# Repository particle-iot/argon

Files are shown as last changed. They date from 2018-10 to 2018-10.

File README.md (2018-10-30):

# Argon

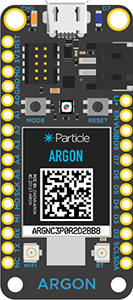
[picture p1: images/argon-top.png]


### Overview

The Argon is a powerful Wi-Fi enabled development board that can act as either a standalone Wi-Fi endpoint or Wi-Fi enabled gateway for Particle Mesh networks. It is based on the Nordic nRF52840 and has built-in battery charging circuitry so it’s easy to connect a Li-Po and deploy your local network in minutes.

The Argon is great for connecting existing projects to the Particle Device Cloud or as a gateway to connect an entire group of local endpoints.

### Features

* Espressif ESP32-D0WD 2.4Ghz Wi-Fi coprocessor 
  * On-board 4MB flash for ESP32 
  * 802.11 b/g/n support 
  * 802.11 n (2.4 GHz), up to 150 Mbps
* Nordic Semiconductor nRF52840 SoC 
  * ARM Cortex-M4F 32-bit processor @ 64MHz 
  * 1MB flash, 256KB RAM 
  * IEEE 802.15.4-2006: 250 Kbps 
  * Bluetooth 5: 2 Mbps, 1 Mbps, 500 Kbps, 125 Kbps 
  * Supports DSP instructions, HW accelerated Floating Point Unit (FPU) calculations 
  * ARM TrustZone CryptoCell-310 Cryptographic and security module 
  * Up to +8 dBm TX power (down to -20 dBm in 4 dB steps) 
  * NFC-A tag
* On-board additional 2MB SPI flash
* 20 mixed signal GPIO (6 x Analog, 8 x PWM), UART, I2C, SPI
* Micro USB 2.0 full speed (12 Mbps)
* Integrated Li-Po charging and battery connector
* JTAG (SWD) Connector
* RGB status LED
* Reset and Mode buttons
* On-board PCB antenna
* u.FL connector for external antenna
* Meets the Adafruit Feather [specification](https://learn.adafruit.com/adafruit-feather/feather-specification) in dimensions and pinout
* FCC, CE and IC certified
* RoHS compliant (lead-free)

### Structure of this repository:
 - /eagle
     + Contains the schematic and PCB files in the Eagle file format
 - /gerbers
     + Contains the manufacturing gerber files for the board
 - /datasheets
     + Contains the relevant datasheets of the components used on the Argon
 - /pdfs
     + Contains schematic files in PDF 

### Hardware datasheet

The complete datasheet for the Argon is available [here.](https://docs.particle.io/datasheets/wi-fi/argon-datasheet/)

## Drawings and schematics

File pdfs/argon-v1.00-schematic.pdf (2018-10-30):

# 15nH MICRO_USB_5P

# CARGB C²¹

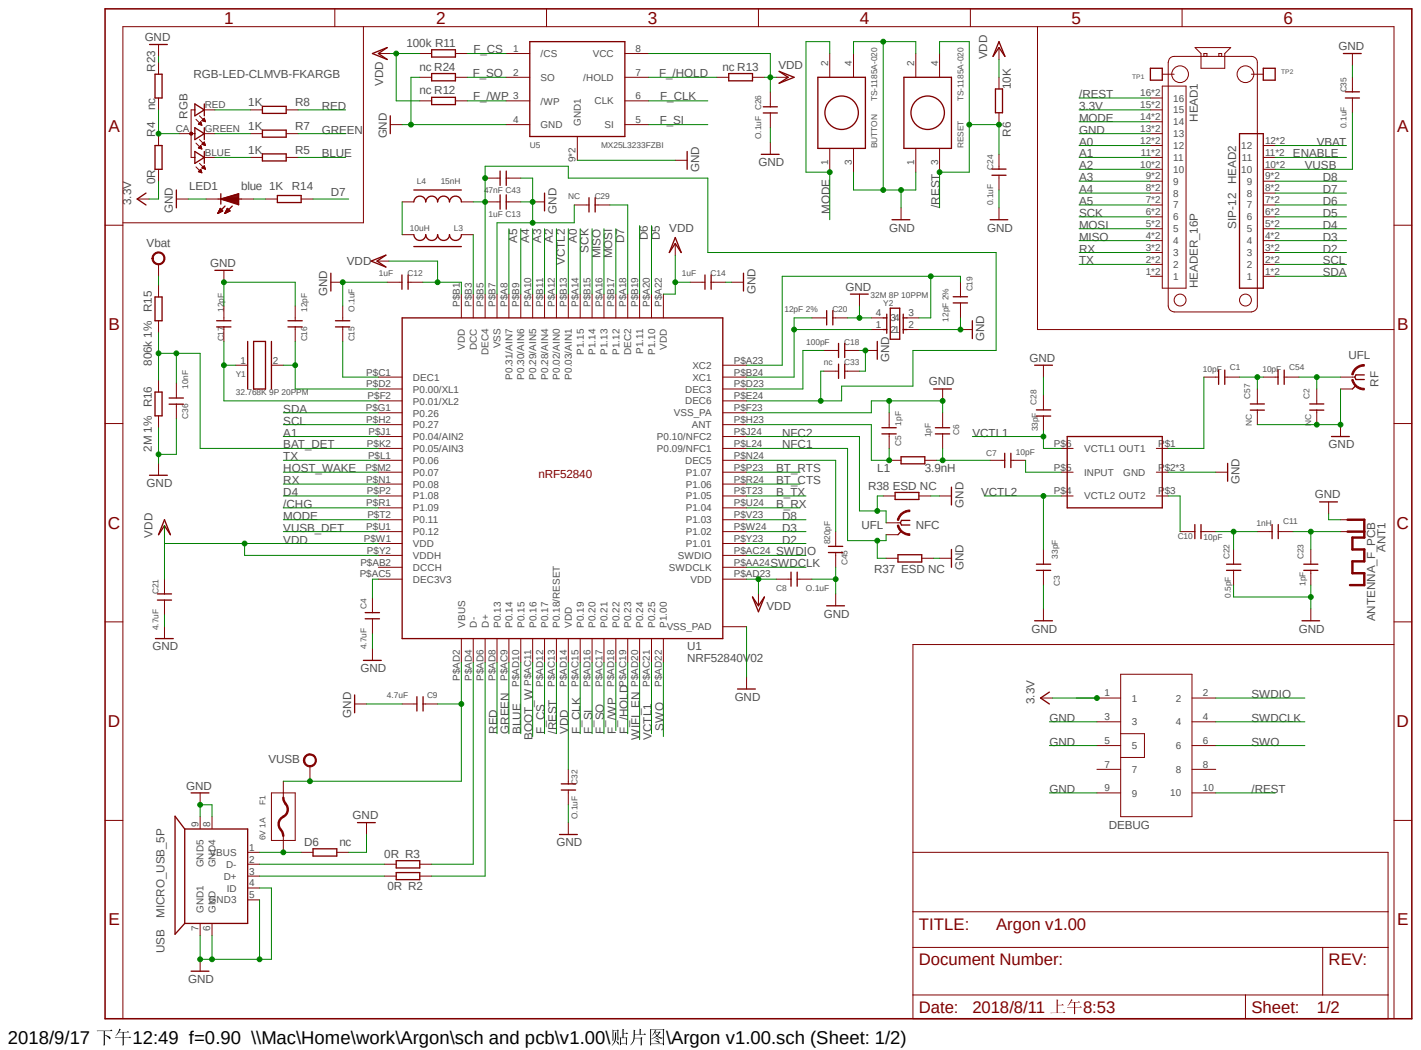
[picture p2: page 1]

GND | | GND

RGB-LED-CLMVB-FKARGB

Document Number: | REV:

Date: 2018/8/11 8:53 | Sheet: 1/2

GND | O.1uF
nc | 10K

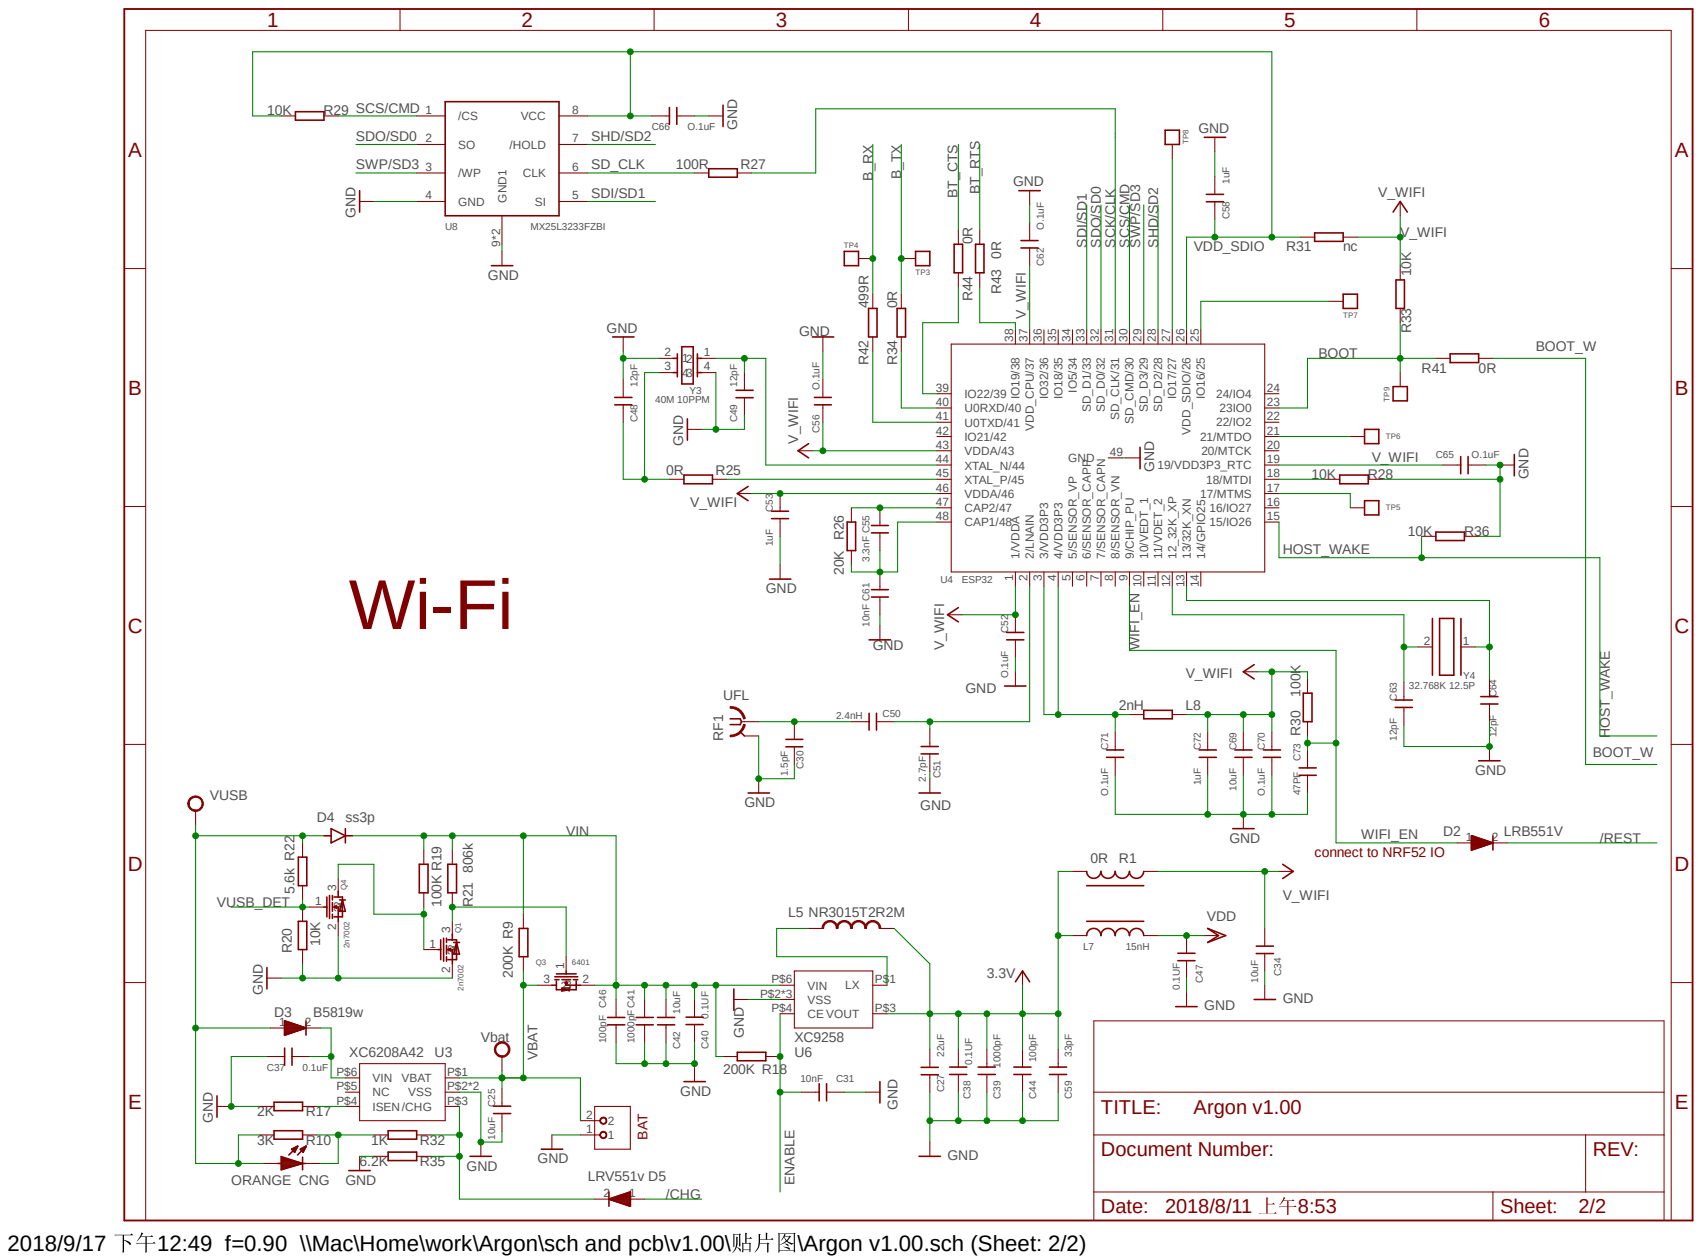
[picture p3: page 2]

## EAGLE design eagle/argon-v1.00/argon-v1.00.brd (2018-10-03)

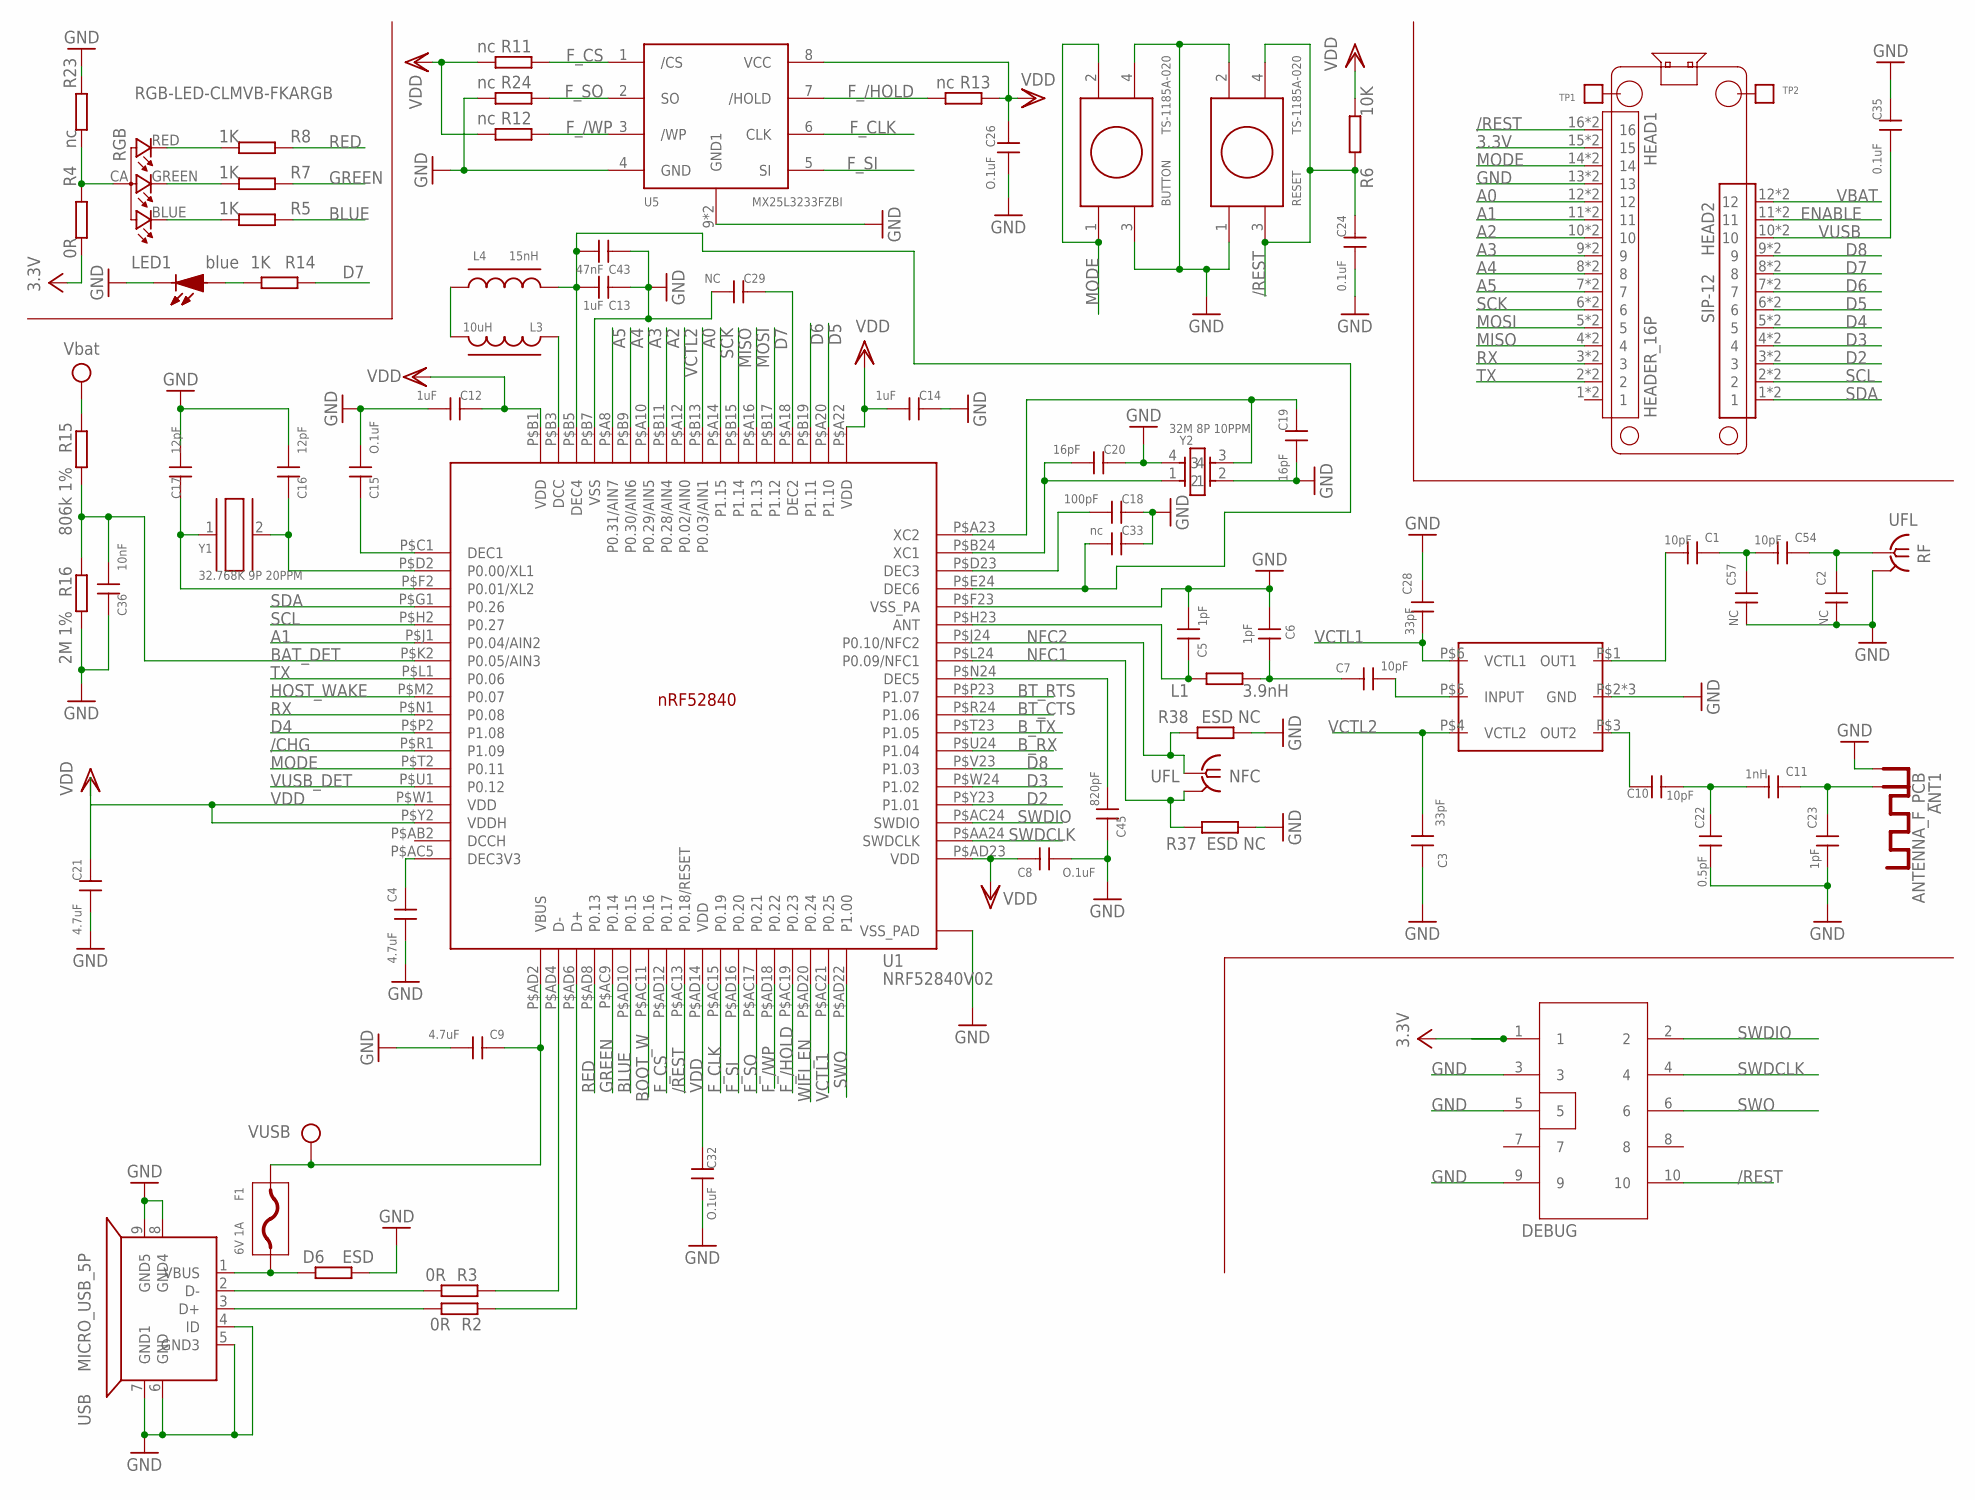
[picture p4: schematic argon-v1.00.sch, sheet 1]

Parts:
ANT1: ANTENNA_F_PCB
BUTTON: TS-1185A-020
C1, C7, C10, C54: 10pF; C-0402
C2, C29, C57: NC; C-0402
C3, C28: 33pF; C-0402
C4, C9, C21: 4.7uF; C-0402
C5, C6, C23: 1pF; C-0402
C8, C15, C26, C32: O.1uF; C-0402
C11: 1nH; C-0402
C12, C13, C14: 1uF; C-0402
C16, C17: 12pF; C-0402
C18: 100pF; C-0402
C19, C20: 16pF; C-0402
C22: 0.5pF; C-0402
C24, C35: 0.1uF; C-0402
C33: nc; C-0402
C36: 10nF; C-0402
C43: 47nF; C-0402
C45: 820pF; C-0402
D6: ESD; R-0402S
DEBUG: CON5X2; CON5X2_1.27
F1: 6V 1A; F0805
HEAD1: HEADER_16P; HEADER_16P2.54
HEAD2: SIP-12
L1: 3.9nH; R-0402S
L3: 10uH; R-0603A
L4: 15nH; R-0402S
LED1: blue; LED0603
NFC: UFL; IPEX-20279-001E
R2, R3, R4: 0R; R-0402S
R5, R7, R8, R14: 1K; R-0402S
R6: 10K; R-0402S
R11, R12, R13, R23, R24: nc; R-0402S
R15: 806k 1%; R-0402S
R16: 2M 1%; R-0402S
R37, R38: ESD NC; R-0402S
RESET: TS-1185A-020
RF: UFL; IPEX-20279-001E
RGB: RGB-LED-CLMVB-FKARGB; PLCC4-2MM-RGB
TP1, TP2: TPTP2.5; TP-2.5
U1: NRF52840V02; AQN507X7X0.85_HA-74_V2
U5: MX25L3233FZBI; USON8-3X4
U$2: SKY13351-378LF; MLPD-6-1X1
USB: MICRO_USB_5P; MICRO_USB
Y1: 32.768K 9P 20PPM; CRY_3215
Y2: 32M 8P 10PPM; CRY_2520

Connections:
3.3V: DEBUG.1, HEAD1.15, HEAD1.P$15 (15), R4.2; also elsewhere on the board
/CHG: U1.P$R1 (P1.09); also elsewhere on the board
/REST: C24.2, DEBUG.10, HEAD1.16, HEAD1.P$16 (16), R6.1, RESET.3, RESET.4, U1.P$AC13 (P0.18/RESET); also elsewhere on the board
A0: HEAD1.12, HEAD1.P$12 (12), U1.P$B13 (P0.03/AIN1)
A1: HEAD1.11, HEAD1.P$11 (11), U1.P$J1 (P0.04/AIN2)
A2: HEAD1.10, HEAD1.P$10 (10), U1.P$B11 (P0.28/AIN4)
A3: HEAD1.9, HEAD1.P$9 (9), U1.P$A10 (P0.29/AIN5)
A4: HEAD1.8, HEAD1.P$8 (8), U1.P$B9 (P0.30/AIN6)
A5: HEAD1.7, HEAD1.P$7 (7), U1.P$A8 (P0.31/AIN7)
BAT_DET: C36.1, R15.2, R16.1, U1.P$K2 (P0.05/AIN3)
BLUE: R5.1, U1.P$AD10 (P0.15)
BOOT_W: U1.P$AC11 (P0.16); also elsewhere on the board
BT_CTS: U1.P$R24 (P1.06); also elsewhere on the board
BT_RTS: U1.P$P23 (P1.07); also elsewhere on the board
B_RX: U1.P$U24 (P1.04); also elsewhere on the board
B_TX: U1.P$T23 (P1.05); also elsewhere on the board
D2: HEAD2.3, HEAD2.P$3 (3), U1.P$Y23 (P1.01)
D3: HEAD2.4, HEAD2.P$4 (4), U1.P$W24 (P1.02)
D4: HEAD2.5, HEAD2.P$5 (5), U1.P$P2 (P1.08)
D5: HEAD2.6, HEAD2.P$6 (6), U1.P$A20 (P1.10)
D6: HEAD2.7, HEAD2.P$7 (7), U1.P$B19 (P1.11)
D7: HEAD2.8, HEAD2.P$8 (8), R14.1, U1.P$B17 (P1.12)
D8: HEAD2.9, HEAD2.P$9 (9), U1.P$V23 (P1.03)
D+: R2.2, USB.3 (D+)
D-: R3.2, USB.2 (D-)
ENABLE: HEAD2.11, HEAD2.P$11 (11); also elsewhere on the board
F_/HOLD: R13.2, U1.P$AC19 (P0.23), U5.7 (/HOLD)
F_/WP: R12.1, U1.P$AD18 (P0.22), U5.3 (/WP)
F_CLK: U1.P$AC15 (P0.19), U5.6 (CLK)
F_CS: R11.1, U1.P$AD12 (P0.17), U5.1 (/CS)
F_SI: U1.P$AD16 (P0.20), U5.5 (SI)
F_SO: R24.1, U1.P$AC17 (P0.21), U5.2 (SO)
GND: ANT1.GND, BUTTON.3, BUTTON.4, C2.2, C3.1, C4.1, C5.1, C6.1, C8.1, C9.1, C12.1, C13.2, C14.2, C15.1, C16.1, C17.1, C18.2, C19.1, C20.2, C21.1, C22.2, C23.2, C24.1, C26.1, C28.1, C29.1, C32.1, C33.2, C35.2, C36.2, C43.2, C45.2, C57.2, D6.1, DEBUG.3, DEBUG.5, DEBUG.9, HEAD1.13, HEAD1.P$13 (13), LED1.2 (K), R16.2, R23.1, R24.2, R37.2, R38.1, RESET.1, RESET.2, RF.2@1 (GND), RF.2@2 (GND), U1.P$74 (VSS_PAD), U1.P$75 (VSS_PAD), U1.P$76 (VSS_PAD), U1.P$77 (VSS_PAD), U1.P$78 (VSS_PAD), U1.P$79 (VSS_PAD), U1.P$80 (VSS_PAD), U1.P$81 (VSS_PAD), U1.P$82 (VSS_PAD), U1.P$85 (VSS_PAD), U1.P$B7 (VSS), U1.P$F23 (VSS_PA), U5.4 (GND), U5.9 (GND1), U5.10 (GND1), U$2.P$2 (GND), U$2.P$7 (GND), U$2.P$8 (GND), USB.4 (ID), USB.5 (GND3), USB.6 (GND), USB.7 (GND1), USB.8 (GND4), USB.9 (GND5), Y2.2, Y2.4; also elsewhere on the board
GREEN: R7.1, U1.P$AC9 (P0.14)
HOST_WAKE: U1.P$M2 (P0.07); also elsewhere on the board
MISO: HEAD1.4, HEAD1.P$4 (4), U1.P$B15 (P1.14)
MODE: BUTTON.1, BUTTON.2, HEAD1.14, HEAD1.P$14 (14), U1.P$T2 (P0.11)
MOSI: HEAD1.5, HEAD1.P$5 (5), U1.P$A16 (P1.13)
unnamed: C5.2, L1.1, U1.P$H23 (ANT)
unnamed: C6.2, C7.2, L1.2
unnamed: C16.2, U1.P$D2 (P0.00/XL1), Y1.2
unnamed: C13.1, C33.1, C43.1, L4.2, U1.P$B5 (DEC4), U1.P$E24 (DEC6)
unnamed: L3.2, L4.1
unnamed: L3.1, U1.P$B3 (DCC)
unnamed: C15.2, U1.P$C1 (DEC1)
unnamed: C17.2, U1.P$F2 (P0.01/XL2), Y1.1
unnamed: C2.1, C54.1, RF.1
unnamed: C19.2, U1.P$A23 (XC2), Y2.3
unnamed: C18.1, U1.P$D23 (DEC3)
unnamed: C10.2, C11.2, C22.1
unnamed: C20.1, U1.P$B24 (XC1), Y2.1
unnamed: C7.1, U$2.P$5 (INPUT)
unnamed: C10.1, U$2.P$3 (OUT2)
unnamed: D6.2, F1.P$1 (1), USB.1 (VBUS)
unnamed: LED1.1 (A), R14.2
unnamed: R8.2, RGB.RED (4)
unnamed: R5.2, RGB.BLUE (2)
unnamed: R7.2, RGB.GREEN (3)
unnamed: C29.2, U1.P$A18 (DEC2)
unnamed: C4.2, U1.P$AC5 (DEC3V3)
unnamed: C45.1, U1.P$N24 (DEC5)
unnamed: C1.2, U$2.P$1 (OUT1)
unnamed: C1.1, C54.2, C57.1
unnamed: R4.1, R23.2, RGB.CA (1)
unnamed: R2.1, U1.P$AD6 (D+)
unnamed: R3.1, U1.P$AD4 (D-)
unnamed: ANT1.RF, C11.1, C23.1
NFC1: NFC.2@1 (GND), NFC.2@2 (GND), R37.1, U1.P$L24 (P0.09/NFC1)
NFC2: NFC.1, R38.2, U1.P$J24 (P0.10/NFC2)
RED: R8.1, U1.P$AD8 (P0.13)
RX: HEAD1.3, HEAD1.P$3 (3), U1.P$N1 (P0.08)
SCK: HEAD1.6, HEAD1.P$6 (6), U1.P$A14 (P1.15)
SCL: HEAD2.2, HEAD2.P$2 (2), U1.P$H2 (P0.27)
SDA: HEAD2.1, HEAD2.P$1 (1), U1.P$G1 (P0.26)
SWDCLK: DEBUG.4, U1.P$AA24 (SWDCLK)
SWDIO: DEBUG.2, U1.P$AC24 (SWDIO)
SWO: DEBUG.6, U1.P$AD22 (P1.00)
TX: HEAD1.2, HEAD1.P$2 (2), U1.P$L1 (P0.06)
VBAT: HEAD2.12, HEAD2.P$12 (12), R15.1; also elsewhere on the board
VCTL1: C28.2, U1.P$AC21 (P0.25), U$2.P$6 (VCTL1)
VCTL2: C3.2, U1.P$A12 (P0.02/AIN0), U$2.P$4 (VCTL2)
VDD: C8.2, C12.2, C14.1, C21.2, C26.2, C32.2, R6.2, R11.2, R12.2, R13.1, U1.P$A22 (VDD), U1.P$AD14 (VDD), U1.P$AD23 (VDD), U1.P$B1 (VDD), U1.P$W1 (VDD), U1.P$Y2 (VDDH), U5.8 (VCC); also elsewhere on the board
VUSB: C9.2, C35.1, F1.P$2 (2), HEAD2.10, HEAD2.P$10 (10), U1.P$AD2 (VBUS); also elsewhere on the board
VUSB_DET: U1.P$U1 (P0.12); also elsewhere on the board
WIFI_EN: U1.P$AD20 (P0.24); also elsewhere on the board

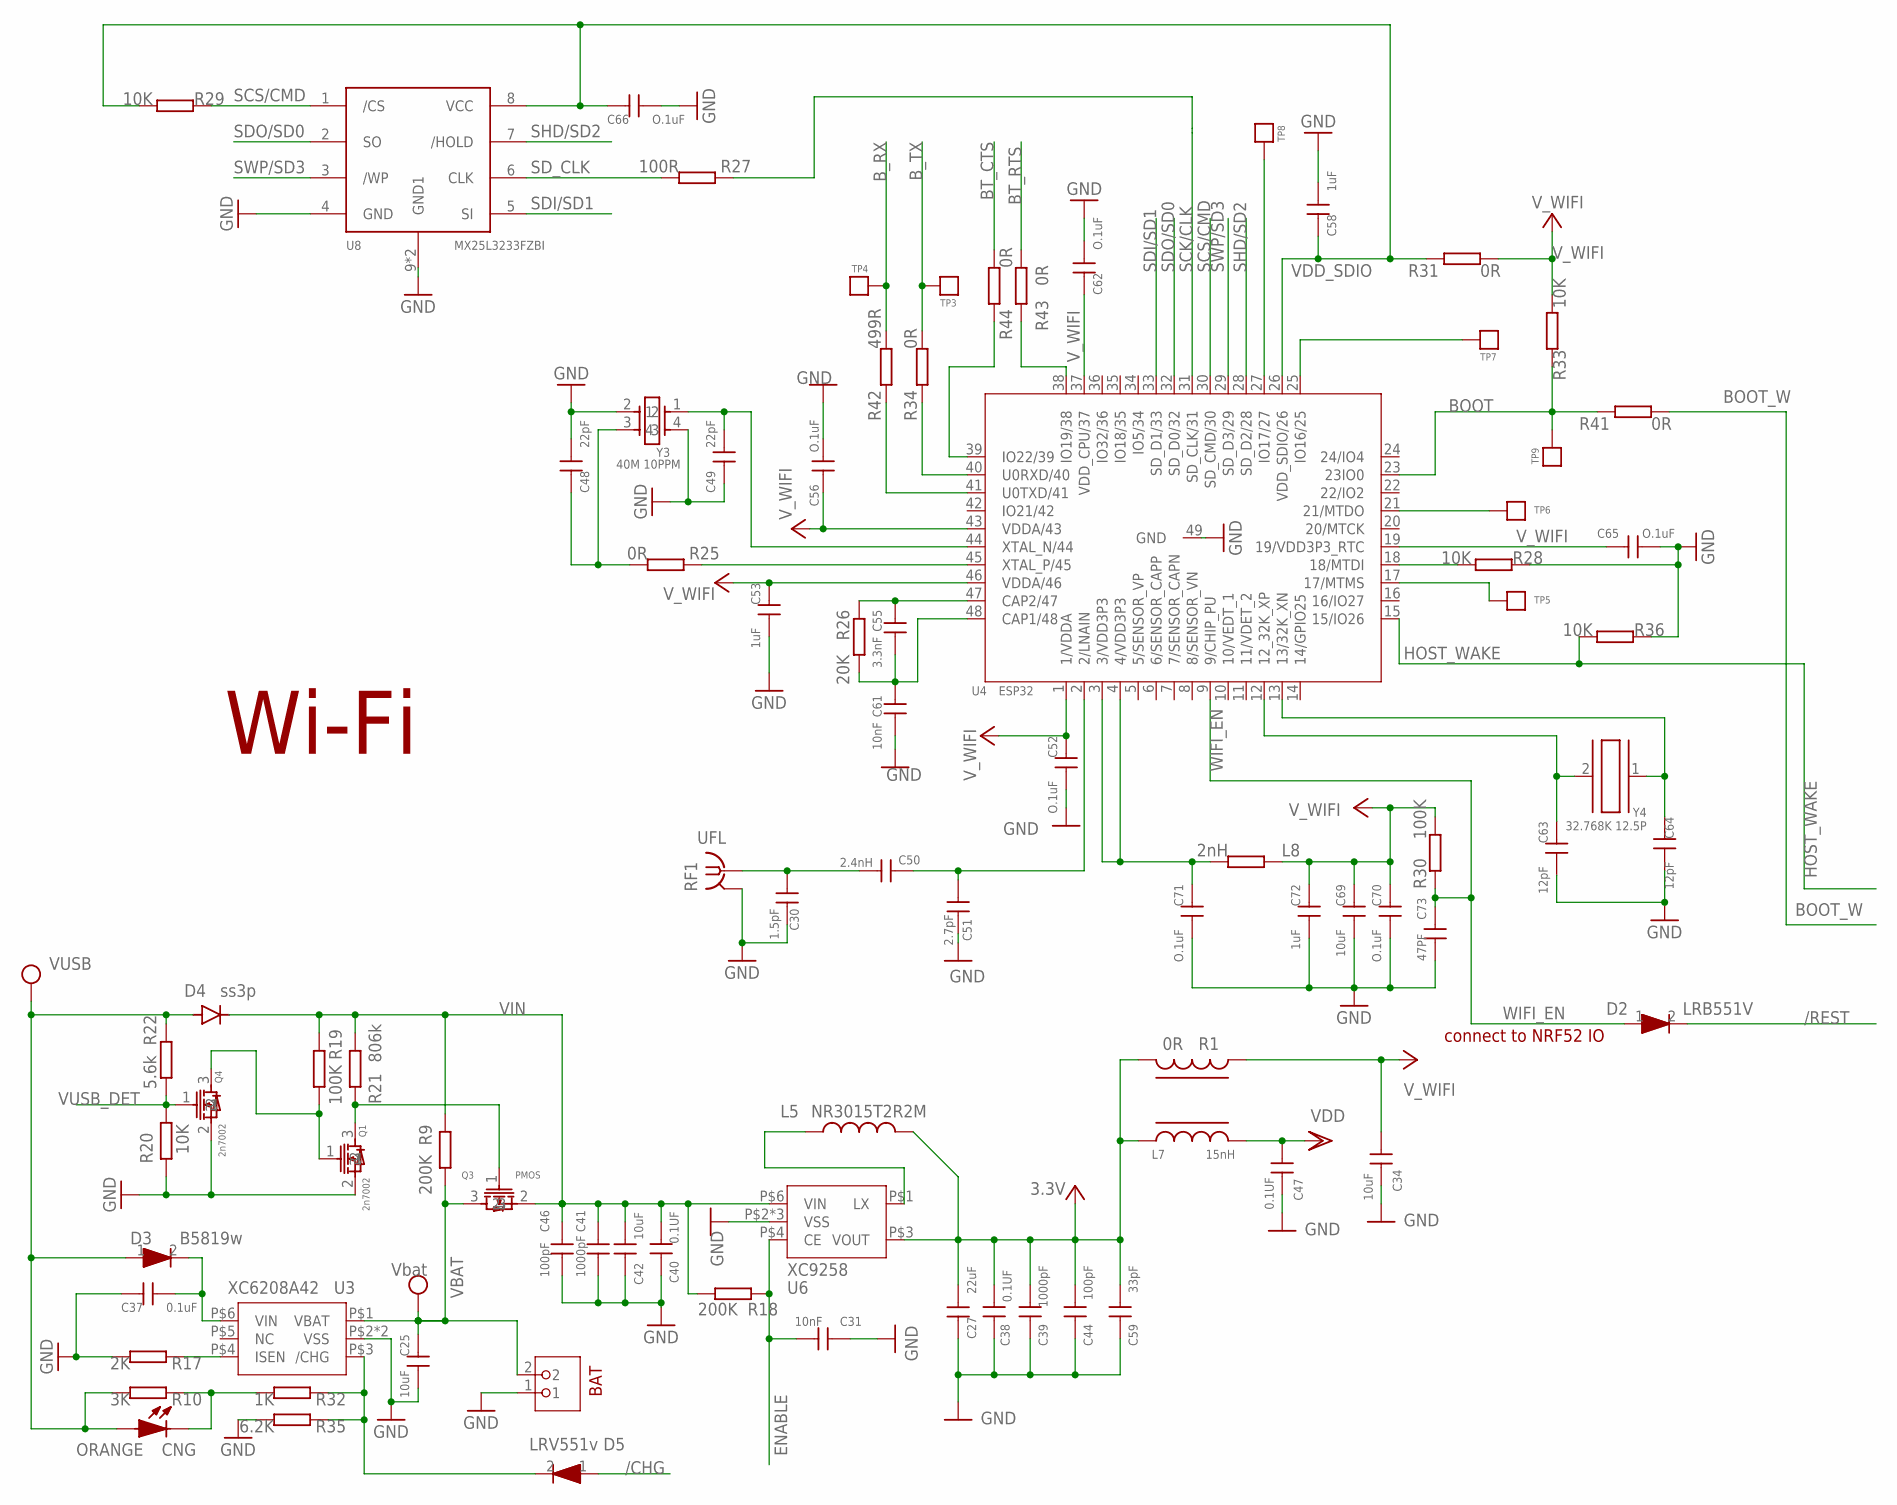
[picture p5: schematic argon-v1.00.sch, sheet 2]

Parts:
BAT: CON2P_SMT; CON_2.0MM_SMT
C25, C69: 10uF; C0805
C27: 22uF; C0805
C30: 1.5pF; C0201-N
C31: 10nF; C-0402
C34, C42: 10uF; C0603
C37: 0.1uF; C-0402
C38, C40, C47: 0.1UF; C-0402
C39, C41: 1000pF; C-0402
C44, C46: 100pF; C-0402
C48, C49: 22pF; C0201-N
C50: 2.4nH; C0201-N
C51: 2.7pF; C0201-N
C52, C56, C62, C65, C66, C70, C71: O.1uF; C-0402
C53, C58, C72: 1uF; C-0402
C55: 3.3nF; C0201-N
C59: 33pF; C-0402
C61: 10nF; C0201-N
C63, C64: 12pF; C-0402
C73: 47PF; C-0402
CNG: ORANGE; LED0603
D2: LRB551V; SOD-323
D3: B5819w; SOD-123
D4: ss3p; DIODE-DO-220AA(SMP)
D5: LRV551v; SOD-323
L5: NR3015T2R2M; INDUCTOR-NR3015
L7: 15nH; R-0402S
L8: 2nH; R-0402S
Q1, Q4: 2n7002; SOT323
Q3: PMOS; SOT-23
R1: 0R; R-0603A
R9, R18: 200K; R-0402S
R10: 3K; R-0402S
R17: 2K; R-0402S
R19, R30: 100K; R-0402S
R20, R28, R29, R33, R36: 10K; R-0402S
R21: 806k; R-0402S
R22: 5.6k; R-0402S
R25: 0R; R0201-N
R26: 20K; R0201-N
R27: 100R; R-0402S
R31, R34, R41, R43, R44: 0R; R-0402S
R32: 1K; R-0402S
R35: 6.2K; R-0402S
R42: 499R; R-0402S
RF1: UFL; IPEX-20279-001E
TP3, TP4, TP5, TP6, TP7, TP8, TP9: TP; TP0.7MM
U3: XC6208A42; USP-6C
U4: ESP32; QFN48-5X5
U6: XC9258; USP-6C
U8: MX25L3233FZBI; USON8-3X4
Y3: 40M 10PPM; CRY_2016
Y4: 32.768K 12.5P; CRY_3215

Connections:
3.3V: C27.1, C38.2, C39.2, C44.2, C59.2, L5.2, L7.1, R1.2, U6.P$3 (VOUT); also elsewhere on the board
/CHG: D5.1; also elsewhere on the board
/REST: D2.2; also elsewhere on the board
BOOT: R33.1, R41.1, TP9.P$1, U4.23 (23IO0)
BOOT_W: R41.2; also elsewhere on the board
BT_CTS: R44.2; also elsewhere on the board
BT_RTS: R43.2; also elsewhere on the board
B_RX: R42.2, TP4.P$1; also elsewhere on the board
B_TX: R34.2, TP3.P$1; also elsewhere on the board
CH: D5.2, R32.1, R35.1, U3.P$3 (/CHG)
ENABLE: C31.2, R18.1, U6.P$4 (CE); also elsewhere on the board
GND: BAT.1, C25.1, C27.2, C30.2, C31.1, C34.2, C37.2, C38.1, C39.1, C40.1, C41.2, C42.2, C44.1, C46.2, C47.2, C48.1, C49.2, C51.1, C52.1, C53.1, C56.1, C58.1, C59.1, C61.1, C62.1, C63.1, C64.1, C65.1, C66.1, C69.1, C70.1, C71.1, C72.1, C73.1, Q1.2, Q4.2, R17.2, R20.1, R28.1, R35.2, R36.1, RF1.2@1 (GND), RF1.2@2 (GND), U3.P$2 (VSS), U3.P$7 (VSS), U4.49 (GND), U6.P$2 (VSS), U6.P$5 (VSS), U6.P$7 (VSS), U8.4 (GND), U8.9 (GND1), U8.10 (GND1), Y3.2, Y3.4; also elsewhere on the board
HOST_WAKE: R36.2, U4.15 (15/IO26); also elsewhere on the board
unnamed: C49.1, U4.44 (XTAL_N/44), Y3.1
unnamed: Q1.1, Q4.3, R19.1
unnamed: R25.1, U4.45 (XTAL_P/45)
unnamed: Q1.3, Q3.1, R21.2
unnamed: TP8.P$1, U4.27 (IO17/27)
unnamed: C55.2, R26.1, U4.47 (CAP2/47)
unnamed: R34.1, U4.40 (U0RXD/40)
unnamed: R17.1, U3.P$4 (ISEN)
unnamed: C30.1, C50.2, RF1.1
unnamed: R42.1, U4.41 (U0TXD/41)
unnamed: CNG.2 (K), R10.1, R32.2
unnamed: R44.1, U4.39 (IO22/39)
unnamed: L5.1, U6.P$1 (LX)
unnamed: C55.1, C61.2, R26.2, U4.48 (CAP1/48)
unnamed: C37.1, D3.2, U3.P$6 (VIN)
unnamed: C71.2, L8.2, U4.3 (3/VDD3P3), U4.4 (4/VDD3P3)
unnamed: TP7.P$1, U4.25 (IO16/25)
unnamed: R28.2, U4.18 (18/MTDI)
unnamed: C63.2, U4.12 (12_32K_XP), Y4.2
unnamed: C64.2, U4.13 (13/32K_XN), Y4.1
unnamed: C48.2, R25.2, Y3.3
unnamed: TP6.P$1, U4.21 (21/MTDO)
unnamed: C50.1, C51.2, U4.2 (2/LNAIN)
unnamed: TP5.P$1, U4.17 (17/MTMS)
unnamed: R43.1, U4.38 (IO19/38)
SCK/CLK: R27.1, U4.31 (SD_CLK/31)
SCS/CMD: R29.1, U4.30 (SD_CMD/30), U8.1 (/CS)
SDI/SD1: U4.33 (SD_D1/33), U8.5 (SI)
SDO/SD0: U4.32 (SD_D0/32), U8.2 (SO)
SD_CLK: R27.2, U8.6 (CLK)
SHD/SD2: U4.28 (SD_D2/28), U8.7 (/HOLD)
SWP/SD3: U4.29 (SD_D3/29), U8.3 (/WP)
VBAT: BAT.2, C25.2, Q3.3, R9.1, U3.P$1 (VBAT); also elsewhere on the board
VDD: C47.1, L7.2; also elsewhere on the board
VDD_SDIO: C58.2, C66.2, R29.2, R31.1, U4.26 (VDD_SDIO/26), U8.8 (VCC)
VIN: C40.2, C41.1, C42.1, C46.1, D4.CATHODE, Q3.2, R9.2, R18.2, R19.2, R21.1, U6.P$6 (VIN)
VUSB: CNG.1 (A), D3.1, D4.ANODE, R10.2, R22.1; also elsewhere on the board
VUSB_DET: Q4.1, R20.2, R22.2; also elsewhere on the board
V_WIFI: C34.1, C52.2, C53.2, C56.2, C62.2, C65.2, C69.2, C70.2, C72.2, L8.1, R1.1, R30.2, R31.2, R33.2, U4.1 (1/VDDA), U4.19 (19/VDD3P3_RTC), U4.37 (VDD_CPU/37), U4.43 (VDDA/43), U4.46 (VDDA/46)
WIFI_EN: C73.2, D2.1, R30.1, U4.9 (9/CHIP_PU); also elsewhere on the board

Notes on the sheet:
Wi-Fi
BAT
connect to NRF52 IO

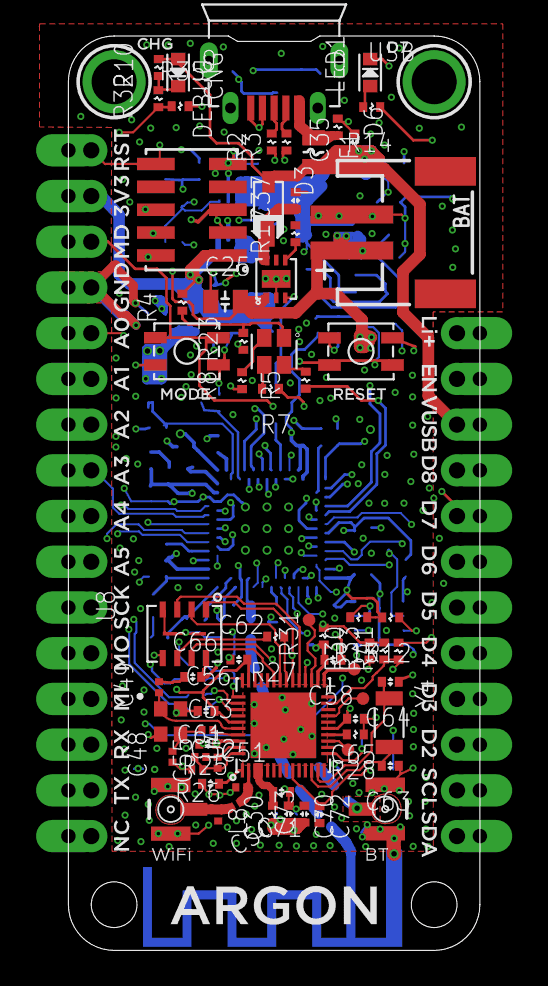
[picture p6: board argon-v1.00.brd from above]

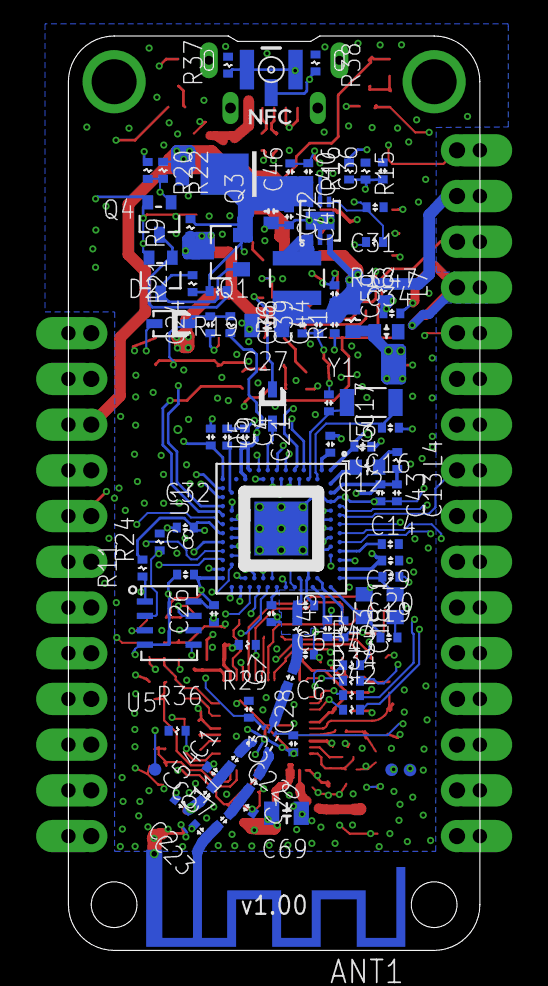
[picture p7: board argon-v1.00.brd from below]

Board: 6 copper layers, 22.9 x 50.8 mm, 161 parts (89 on the bottom side), 122 nets.

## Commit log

2018-10-03 added design files
    [argon-v1.00.brd, argon-v1.00.sch]
2019-03-04 Include MX25L3233F SPI flash datasheet
